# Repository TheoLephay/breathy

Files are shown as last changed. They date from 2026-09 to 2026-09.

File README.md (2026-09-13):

# Breathy

Work in progress.

An IOT esp32-based, battery powered, air quality monitor.

Since this is the least original project but I still needed one, I decided to make the li-ion charger myself as a challenge with discreet components.

Hardware design sheets available under `hardware/breathy/` folder. SPICE sim under `hardware/spice_sims/`.

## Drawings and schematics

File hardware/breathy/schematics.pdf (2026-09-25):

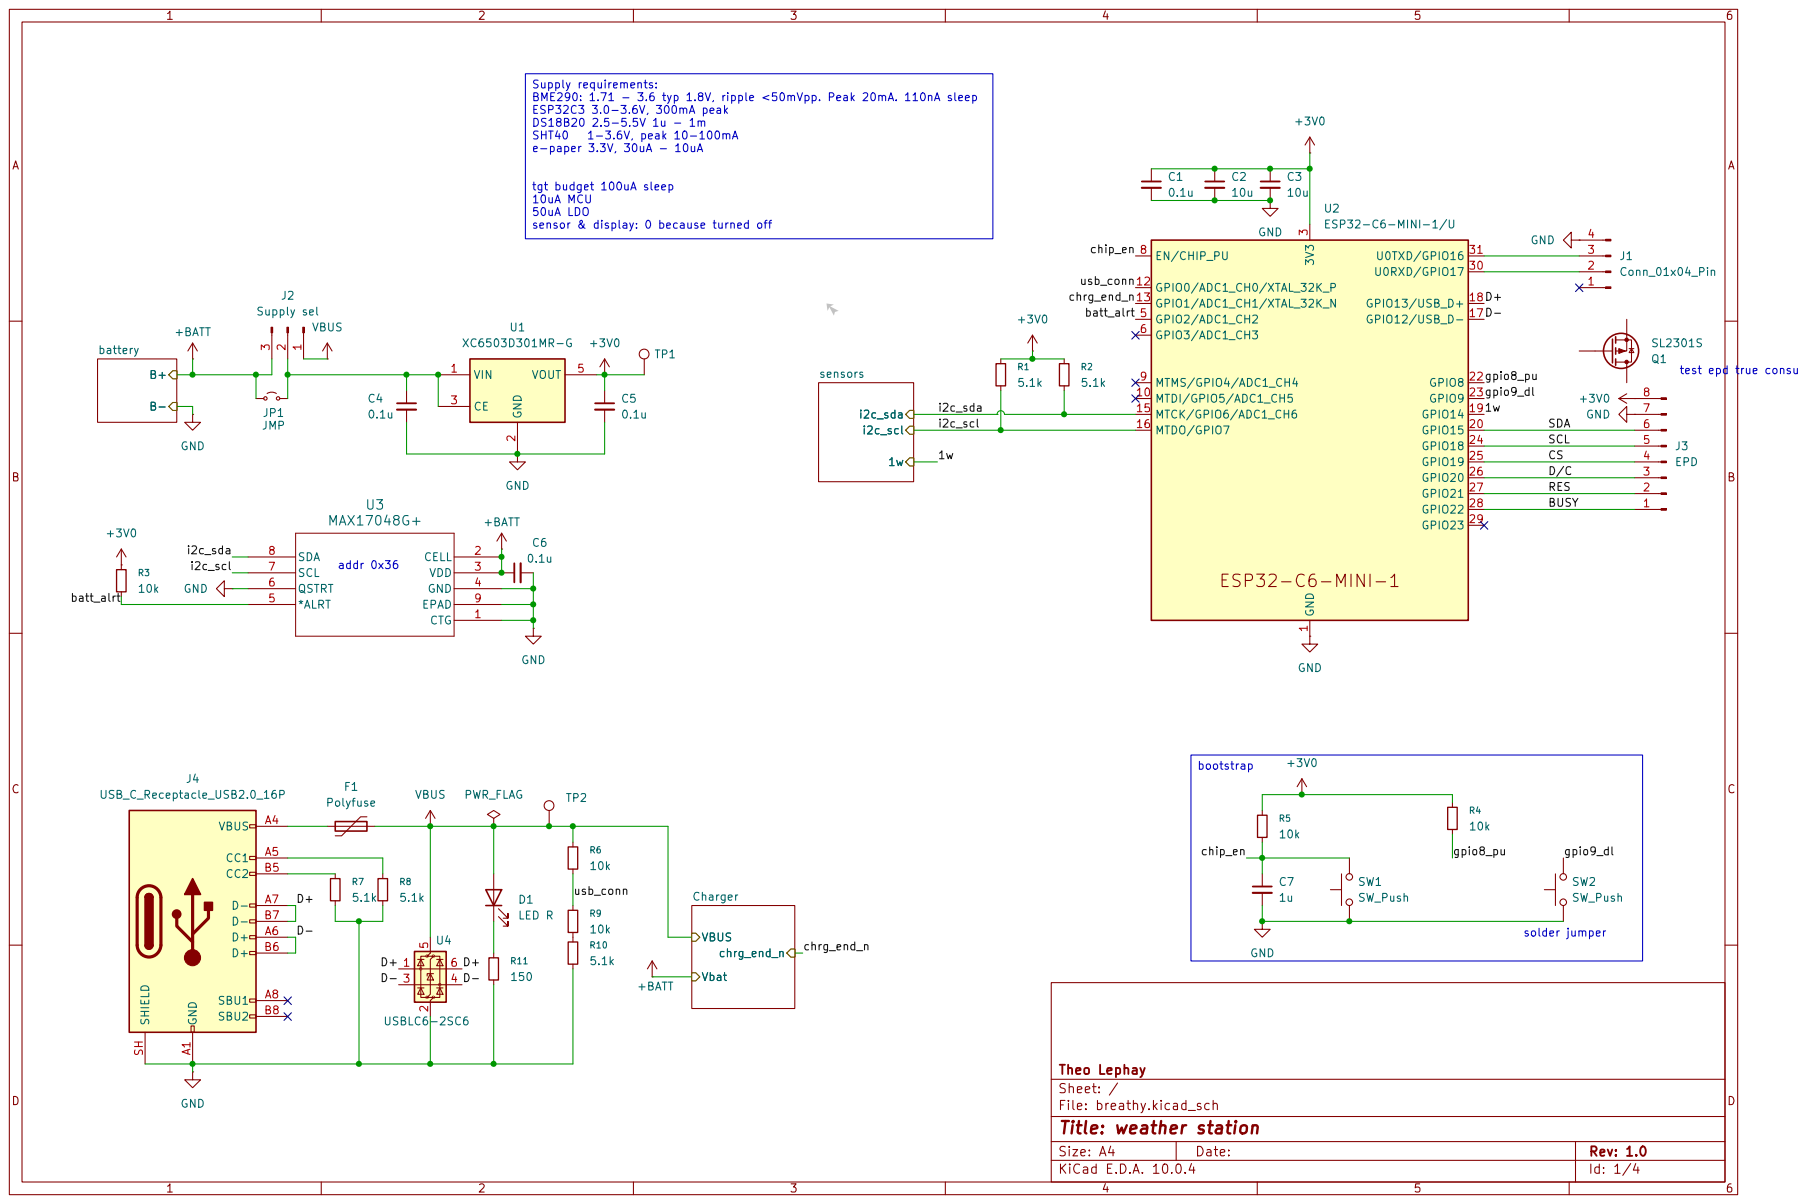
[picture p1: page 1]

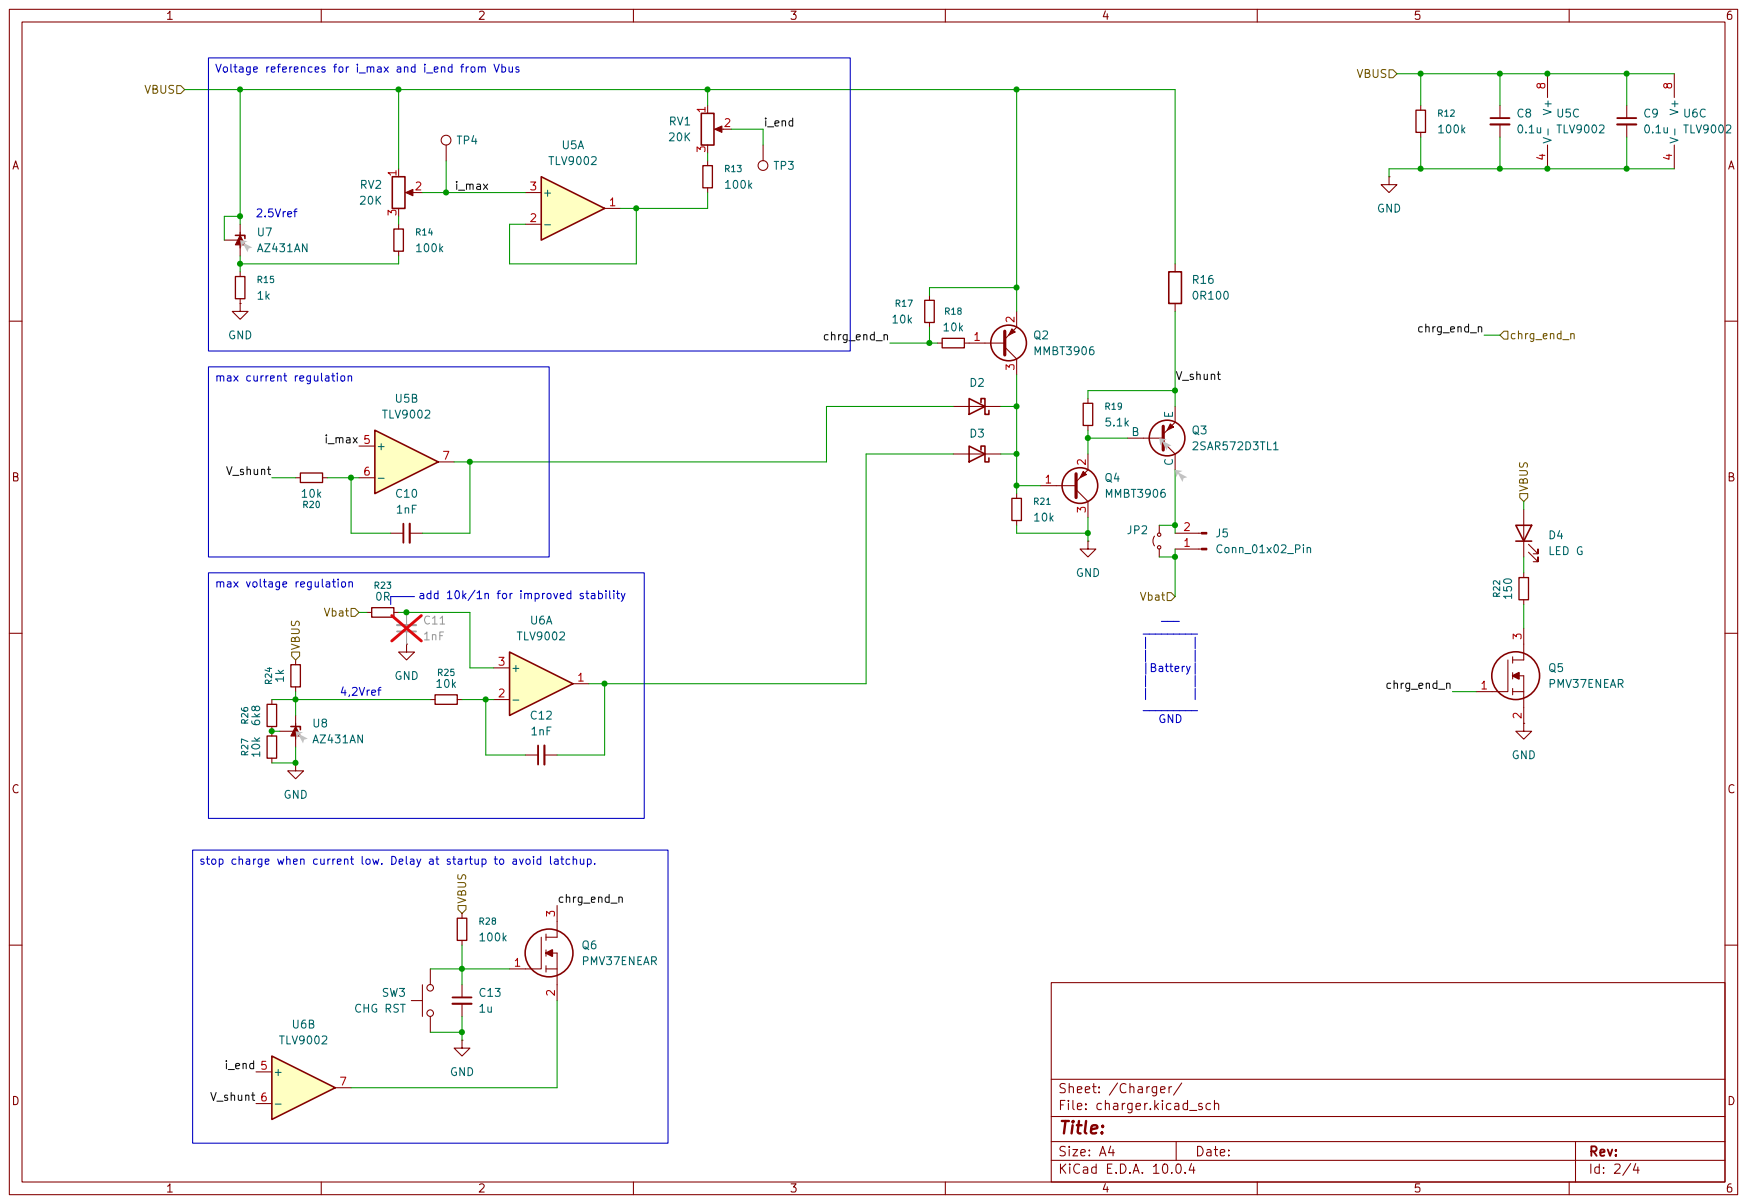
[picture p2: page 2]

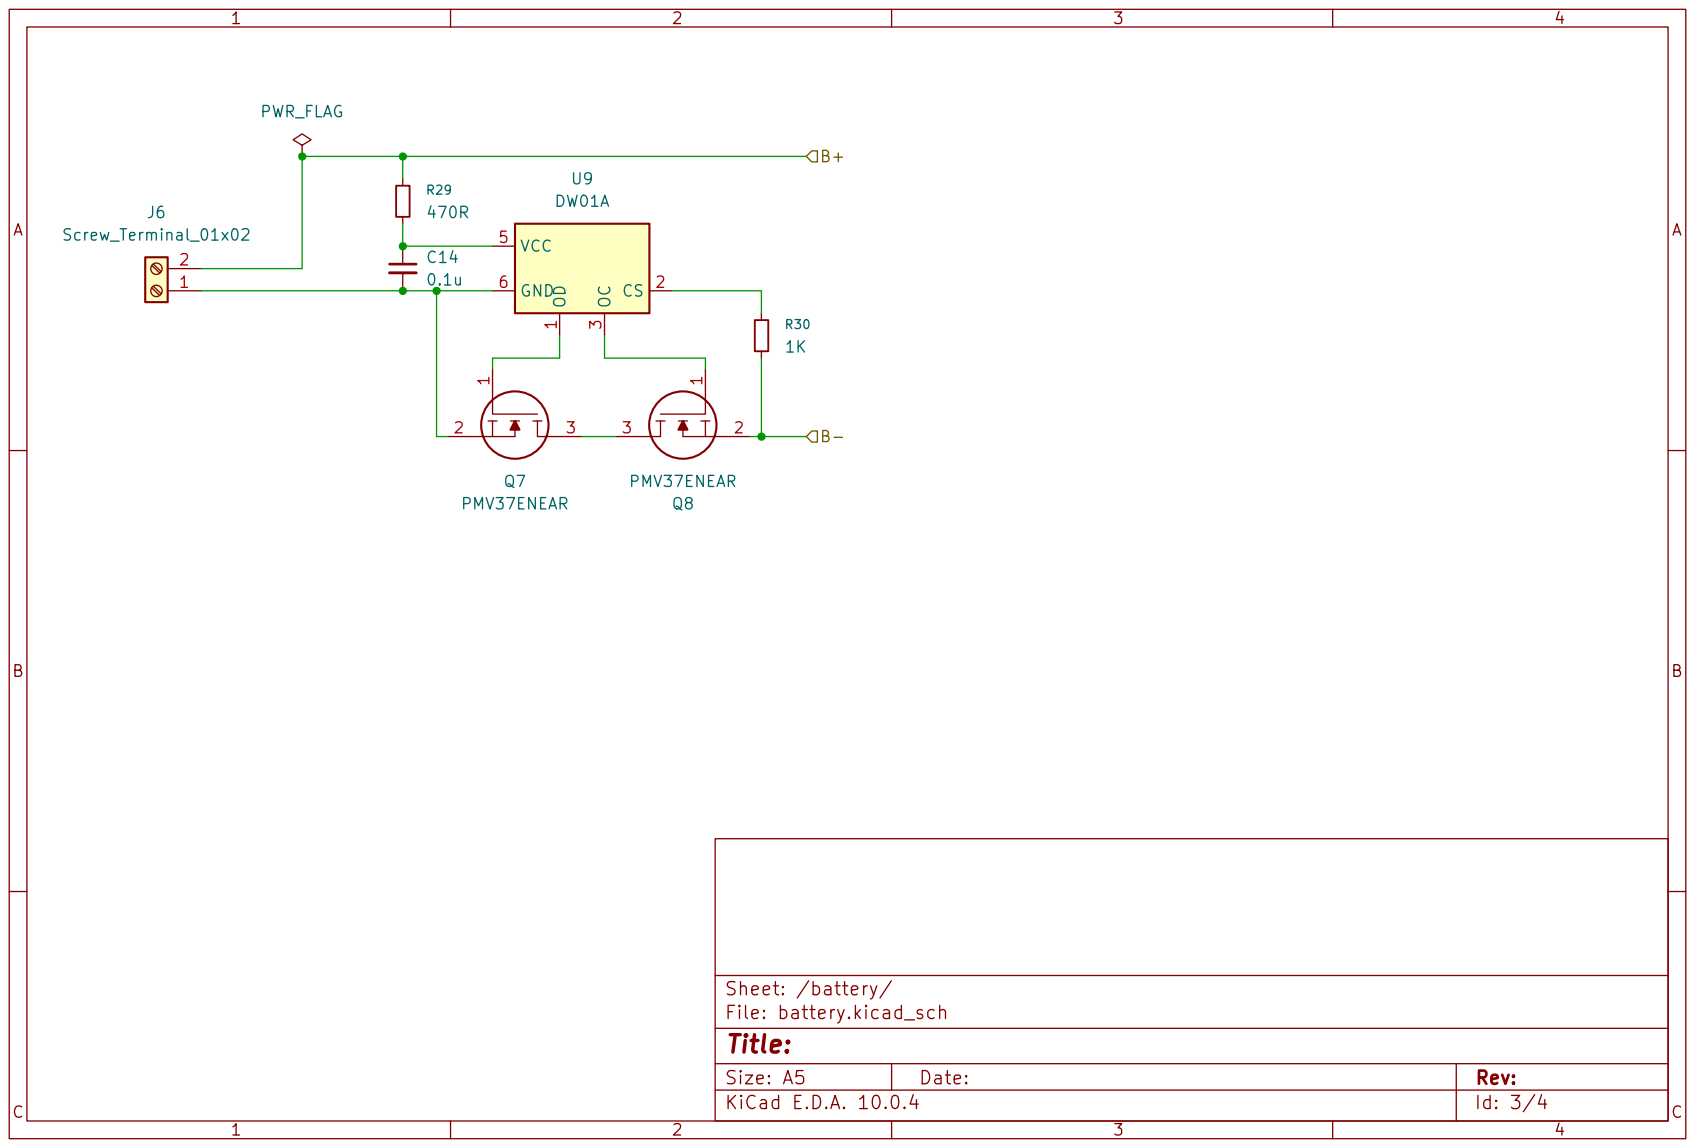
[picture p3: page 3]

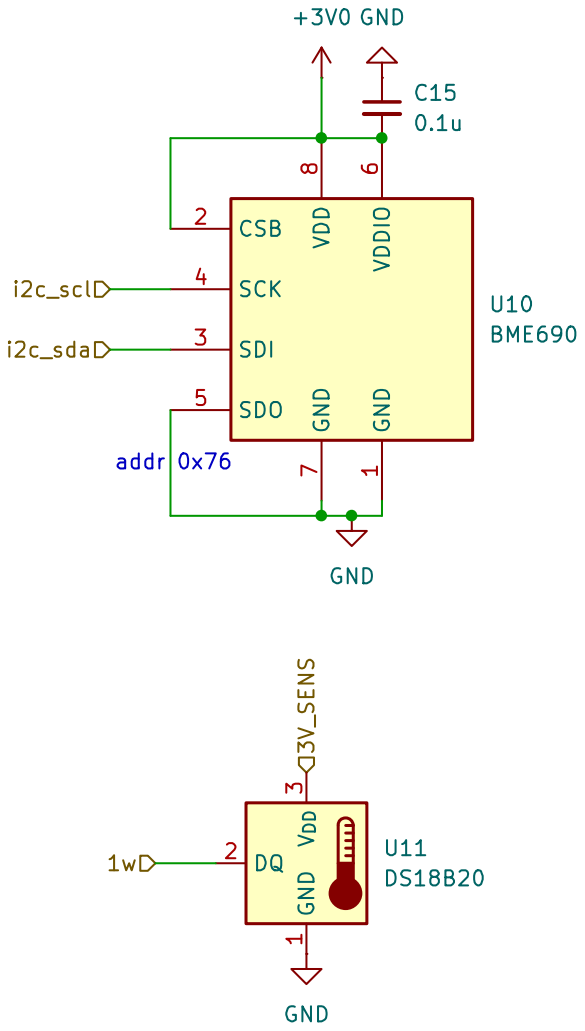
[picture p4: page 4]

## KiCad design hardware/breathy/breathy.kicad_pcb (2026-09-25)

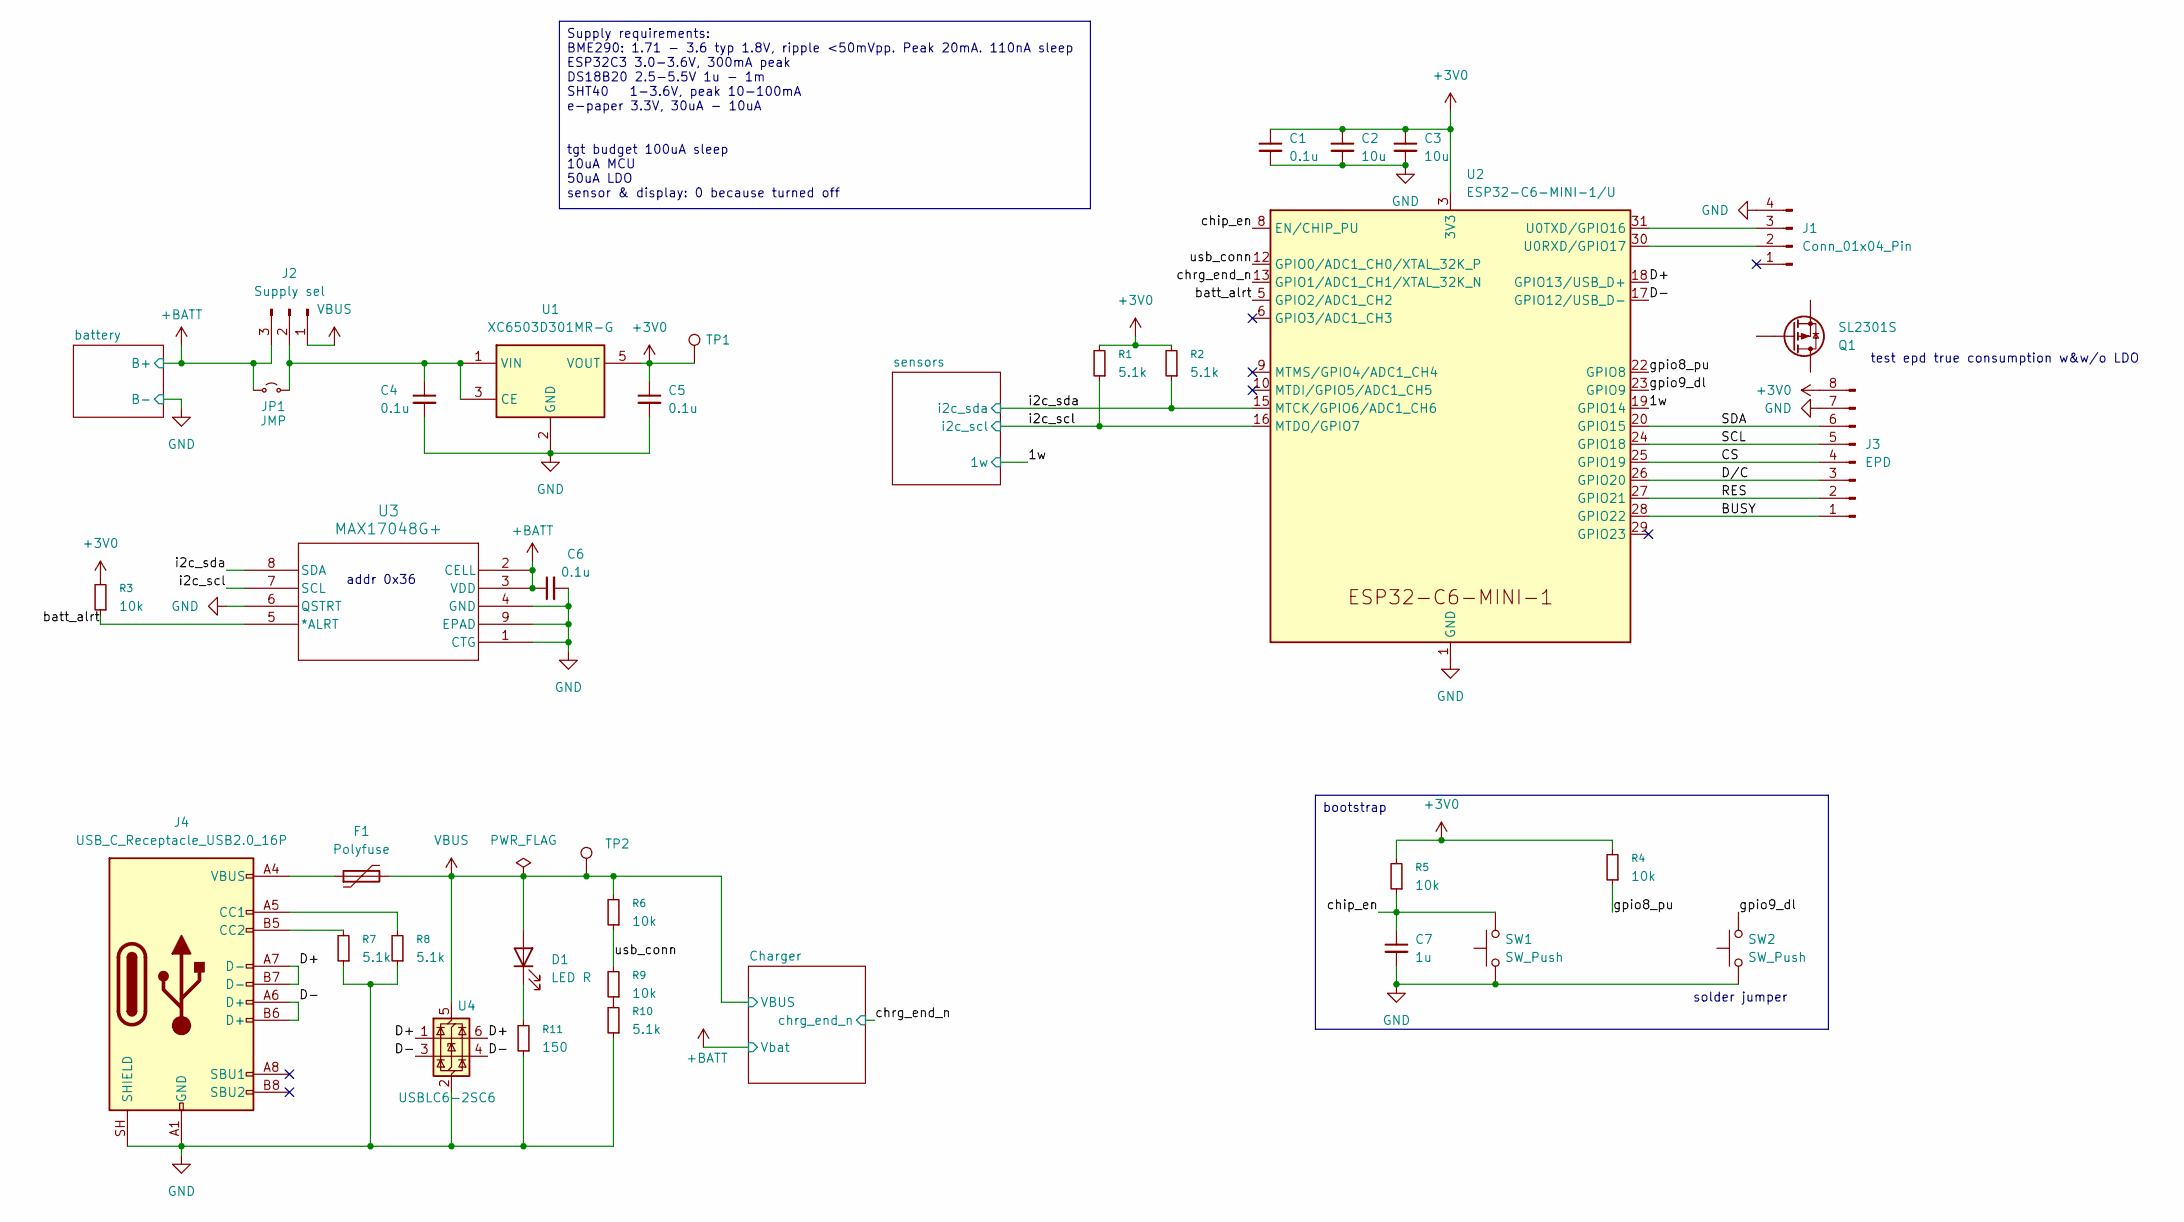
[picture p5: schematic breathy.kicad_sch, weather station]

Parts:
C1, C4, C5, C6: 0.1u; C_0805_2012Metric
C2, C3: 10u; C_1206_3216Metric
C7: 1u; C_1206_3216Metric
D1: LED R; LED_1206_3216Metric
F1: Polyfuse; C_1206_3216Metric
J1: Conn_01x04_Pin; PinHeader_1x04_P2.54mm_Vertical
J2: Supply sel; PinHeader_1x03_P2.54mm_Vertical
J3: EPD; PinHeader_1x08_P2.54mm_Horizontal
J4: USB_C_Receptacle_USB2.0_16P; USB_C_Receptacle_GCT_USB4105-xx-A_16P_TopMnt_Horizontal
JP1: JMP; SolderJumper-2_P1.3mm_Open_TrianglePad1.0x1.5mm
Q1: SL2301S; SOT-23
R1, R2, R7, R8, R10: 5.1k; R_0805_2012Metric
R3, R4, R5, R6, R9: 10k; R_0805_2012Metric
R11: 150; R_0805_2012Metric
SW1: SW_Push; SW_Push_1P1T_NO_CK_KSC9xxG
SW2: SW_Push; SolderJumper-2_P1.3mm_Open_TrianglePad1.0x1.5mm
TP1, TP2: TestPoint; TestPoint_Pad_D1.5mm
U1: XC6503D301MR-G; SC-74A-5_1.55x2.9mm_P0.95mm
U2: ESP32-C6-MINI-1/U; ESP32-C6-MINI-1
U3: MAX17048G+; 21-0168_T822&plus_3_MXM-M
U4: USBLC6-2SC6; SOT-23-6

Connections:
+3V0: C1.1, C2.1, C3.1, C5.1, J3.8, R1.2, R2.2, R3.2, R4.2, R5.2, TP1.1 (1_1), U1.5 (VOUT), U2.3 (3V3); also elsewhere on the board
+BATT: C6.1, J2.3, JP1.1 (A), U3.2 (CELL), U3.3 (VDD); also elsewhere on the board
/1w: U2.19 (GPIO14); also elsewhere on the board
/BUSY: J3.1, U2.28 (GPIO22)
/CS: J3.4, U2.25 (GPIO19)
/D+: J4.A7 (D-), J4.B7 (D-), U2.18 (GPIO13/USB_D+), U4.1 (I/O1), U4.6 (I/O1)
/D-: J4.A6 (D+), J4.B6 (D+), U2.17 (GPIO12/USB_D-), U4.3 (I/O2), U4.4 (I/O2)
/D/C: J3.3, U2.26 (GPIO20)
/RES: J3.2, U2.27 (GPIO21)
/SCL: J3.5, U2.24 (GPIO18)
/SDA: J3.6, U2.20 (GPIO15)
/batt_alrt: R3.1, U2.5 (GPIO2/ADC1_CH2), U3.5 (*ALRT)
/chip_en: C7.1, R5.1, SW1.2, U2.8 (EN/CHIP_PU)
/chrg_end_n: U2.13 (GPIO1/ADC1_CH1/XTAL_32K_N); also elsewhere on the board
/gpio8_pu: R4.1, U2.22 (GPIO8)
/gpio9_dl: SW2.2, U2.23 (GPIO9)
/i2c_scl: R1.1, U2.16 (MTDO/GPIO7), U3.7 (SCL); also elsewhere on the board
/i2c_sda: R2.1, U2.15 (MTCK/GPIO6/ADC1_CH6), U3.8 (SDA); also elsewhere on the board
/usb_conn: R6.1, R9.2, U2.12 (GPIO0/ADC1_CH0/XTAL_32K_P)
GND: C1.2, C2.2, C3.2, C4.2, C5.2, C6.2, C7.2, J1.4, J3.7, J4.A1 (GND), J4.A12 (GND), J4.B1 (GND), J4.B12 (GND), J4.SH (SHIELD), R7.1, R8.1, R10.1, R11.1, SW1.1, SW2.1, U1.2 (GND), U2.1 (GND), U2.2 (GND), U2.11 (GND), U2.14 (GND), U2.36 (GND), U2.37 (GND), U2.38 (GND), U2.39 (GND), U2.40 (GND), U2.41 (GND), U2.42 (GND), U2.43 (GND), U2.44 (GND), U2.45 (GND), U2.46 (GND), U2.47 (GND), U2.48 (GND), U2.49 (GND), U2.50 (GND), U2.51 (GND), U2.52 (GND), U2.53 (GND), U3.1 (CTG), U3.4 (GND), U3.6 (QSTRT), U3.9 (EPAD), U4.2 (GND); also elsewhere on the board
unnamed: D1.1 (K), R11.2
unnamed: F1.1, J4.A4 (VBUS), J4.A9 (VBUS), J4.B4 (VBUS), J4.B9 (VBUS)
unnamed: J1.2, U2.30 (U0RXD/GPIO17)
unnamed: J1.3, U2.31 (U0TXD/GPIO16)
unnamed: C4.1, J2.2, JP1.2 (B), U1.1 (VIN), U1.3 (CE)
unnamed: J4.A5 (CC1), R8.2
unnamed: J4.B5 (CC2), R7.2
unnamed: R9.1, R10.2
VBUS: D1.2 (A), F1.2, J2.1, R6.2, TP2.1 (1_1), U4.5 (VBUS); also elsewhere on the board

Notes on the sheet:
solder jumper
test epd true consumption w&w/o LDO
addr 0x36
Supply requirements: BME290: 1.71 - 3.6 typ 1.8V, ripple <50mVpp. Peak 20mA. 110nA sleep ESP32C3 3.0-3.6V, 300mA peak DS18B20 2.5-5.5V 1u - 1m SHT40 1-3.6V, peak 10-100mA e-paper 3.3V, 30uA - 10uA tgt budget 100uA sleep 10uA MCU 50uA LDO sensor & display: 0 because turned off
bootstrap

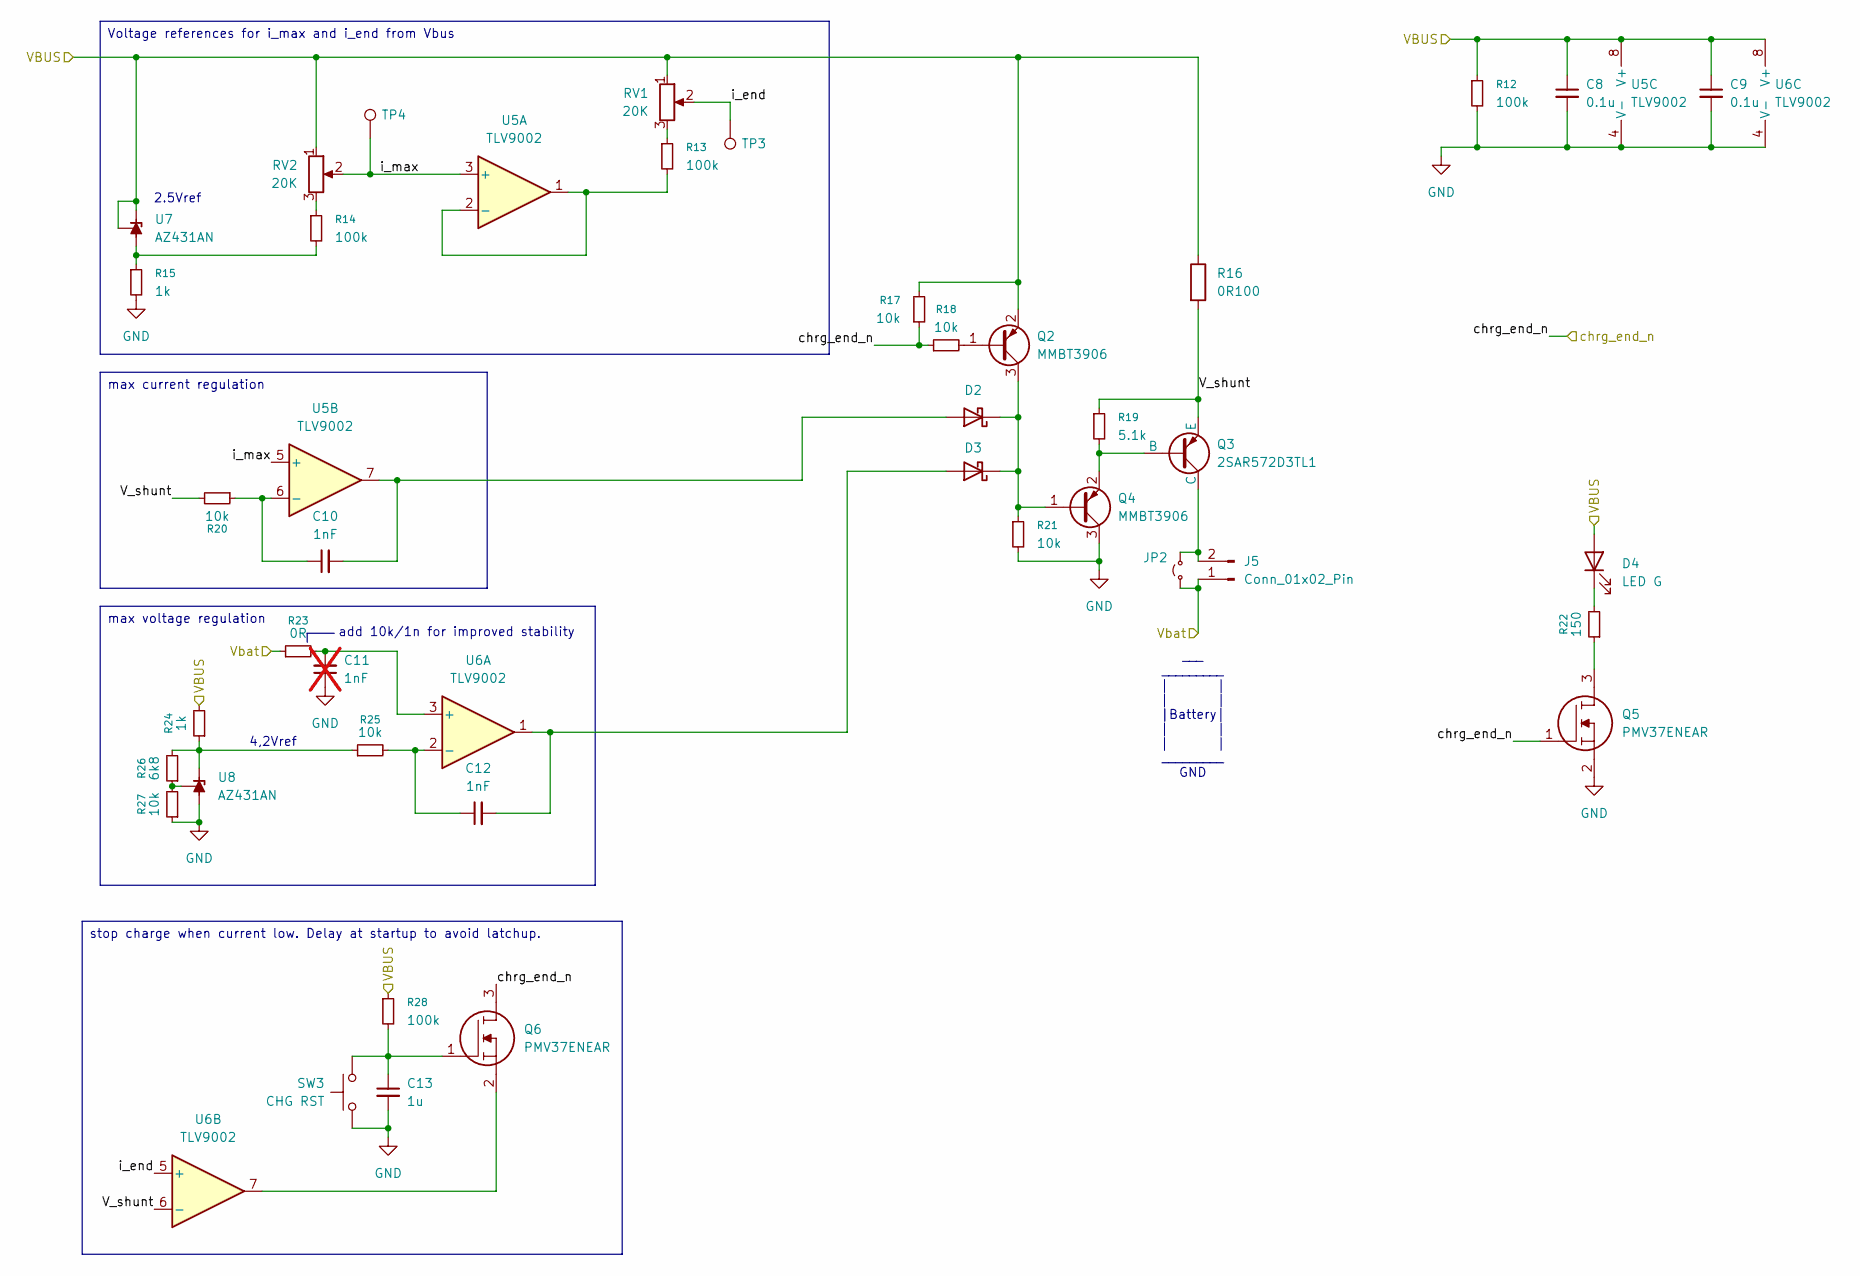
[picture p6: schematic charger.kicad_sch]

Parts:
C8, C9: 0.1u; C_0805_2012Metric
C10, C12: 1nF; C_0805_2012Metric
C11: 1nF; C_0805_2012Metric; not fitted
C13: 1u; C_1206_3216Metric
D2, D3: D_Schottky; D_SOD-323_HandSoldering
D4: LED G; LED_1206_3216Metric
J5: Conn_01x02_Pin; PinHeader_1x02_P2.54mm_Vertical
JP2: Jumper_2_Small_Open; SolderJumper-2_P1.3mm_Open_TrianglePad1.0x1.5mm
Q2, Q4: MMBT3906; SOT-23
Q3: 2SAR572D3TL1; TO-252-2
Q5, Q6: PMV37ENEAR; SOT95P230X110-3N; Mouser Part Number 771-PMV37ENEAR
R12, R13, R14, R28: 100k; R_1206_3216Metric
R15, R24: 1k; R_1206_3216Metric
R16: 0R100; R_2010_5025Metric_Pad1.40x2.65mm_HandSolder
R17, R18, R20, R21, R25, R27: 10k; R_0805_2012Metric
R19: 5.1k; R_0805_2012Metric
R22: 150; R_0805_2012Metric
R23: 0R; R_0805_2012Metric
R26: 6k8; R_0805_2012Metric
RV1, RV2: 20K; Potentiometer_Bourns_TC33X_Vertical
SW3: CHG RST; SW_Push_1P1T_NO_CK_KSC9xxG
TP3, TP4: TestPoint; TestPoint_Pad_D1.5mm
U5, U6: TLV9002; TSOT-23-8
U7, U8: AZ431AN; SOT-23

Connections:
+BATT: J5.1, JP2.1 (A), R23.1; also elsewhere on the board
/Charger/V_shunt: Q3.3 (E), R16.2, R19.1, R20.2, U6.6 (-)
/Charger/i_end: RV1.2, TP3.1 (1_1), U6.5 (+)
/Charger/i_max: RV2.2, TP4.1 (1_1), U5.3 (+), U5.5 (+)
/chrg_end_n: Q5.1, Q6.3, R17.1, R18.1; also elsewhere on the board
GND: C8.2, C9.2, C11.1, C13.2, Q4.3 (C), Q5.2, R12.2, R15.2, R21.2, R27.1, SW3.1, U5.4 (V-), U6.4 (V-), U8.3 (A); also elsewhere on the board
unnamed: C13.1, Q6.1, R28.2, SW3.2
unnamed: C10.2, D2.2 (A), U5.7
unnamed: D2.1 (K), D3.1 (K), Q2.3 (C), Q4.1 (B), R21.1
unnamed: C12.2, D3.2 (A), U6.1
unnamed: D4.1 (K), R22.2
unnamed: J5.2, JP2.2 (B), Q3.2 (C)
unnamed: Q2.1 (B), R18.2
unnamed: Q3.1 (B), Q4.2 (E), R19.2
unnamed: Q5.3, R22.1
unnamed: Q6.2, U6.7
unnamed: R13.1, RV1.3
unnamed: R14.1, RV2.3
unnamed: R13.2, U5.1, U5.2 (-)
unnamed: C10.1, R20.1, U5.6 (-)
unnamed: C11.2, R23.2, U6.3 (+)
unnamed: C12.1, R25.2, U6.2 (-)
unnamed: R14.2, R15.1, U7.3 (A)
unnamed: R24.1, R25.1, R26.2, U8.2 (K)
unnamed: R26.1, R27.2, U8.1 (REF)
VBUS: C8.1, C9.1, D4.2 (A), Q2.2 (E), R12.1, R16.1, R17.2, R24.2, R28.1, RV1.1, RV2.1, U5.8 (V+), U6.8 (V+), U7.1 (REF), U7.2 (K); also elsewhere on the board

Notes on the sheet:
___ _________ | | | | |Battery| | | | | _________ GND
2.5Vref
add 10k/1n for improved stability
4,2Vref
stop charge when current low. Delay at startup to avoid latchup.
Voltage references for i_max and i_end from Vbus
max current regulation
max voltage regulation

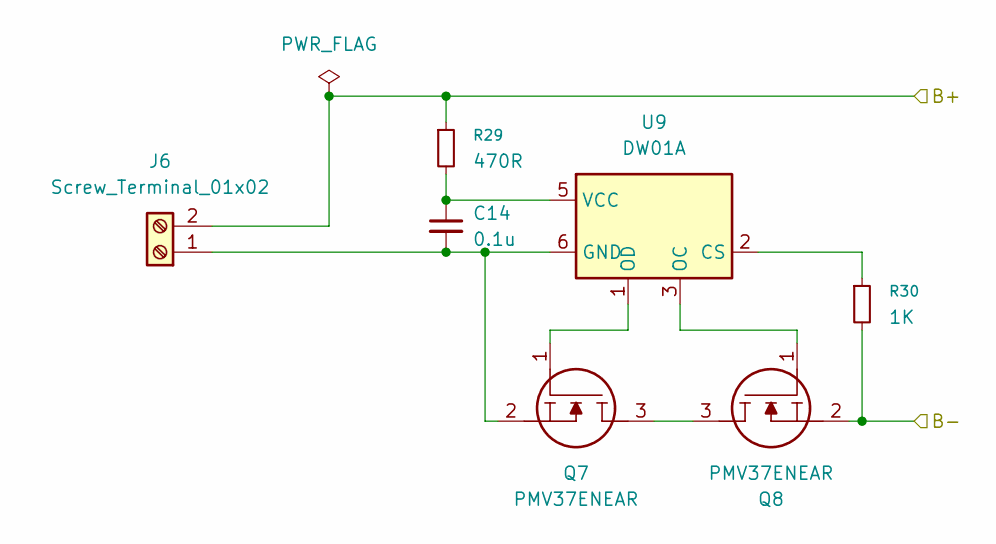
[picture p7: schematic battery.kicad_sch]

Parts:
C14: 0.1u; C_0805_2012Metric
J6: Screw_Terminal_01x02; TerminalBlock_MaiXu_MX126-5.0-02P_1x02_P5.00mm
Q7, Q8: PMV37ENEAR; SOT95P230X110-3N; Mouser Part Number 771-PMV37ENEAR
R29: 470R; R_0805_2012Metric
R30: 1K; R_1206_3216Metric
U9: DW01A; SOT-23-6

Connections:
+BATT: J6.2, R29.1; also elsewhere on the board
GND: Q8.2, R30.2; also elsewhere on the board
unnamed: C14.2, J6.1, Q7.2, U9.6 (GND)
unnamed: Q7.3, Q8.3
unnamed: R30.1, U9.2 (CS)
unnamed: Q8.1, U9.3 (OC)
unnamed: Q7.1, U9.1 (OD)
unnamed: C14.1, R29.2, U9.5 (VCC)

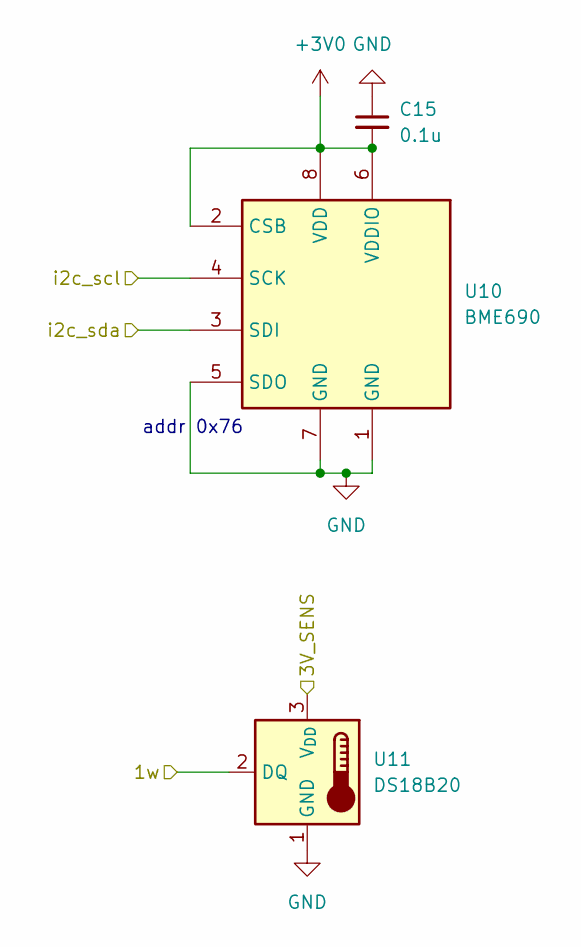
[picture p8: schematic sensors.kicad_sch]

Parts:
C15: 0.1u; C_0805_2012Metric
U10: BME690; Bosch_LGA-8_3x3mm_P0.8mm_ClockwisePinNumbering
U11: DS18B20; TO-92_Inline

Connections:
+3V0: C15.2, U10.2 (CSB), U10.6 (VDDIO), U10.8 (VDD); also elsewhere on the board
/1w: U11.2 (DQ); also elsewhere on the board
/i2c_scl: U10.4 (SCK); also elsewhere on the board
/i2c_sda: U10.3 (SDI); also elsewhere on the board
/sensors/3V_SENS: U11.3 (V_{DD})
GND: C15.1, U10.1 (GND), U10.5 (SDO), U10.7 (GND), U11.1 (GND); also elsewhere on the board

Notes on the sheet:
addr 0x76

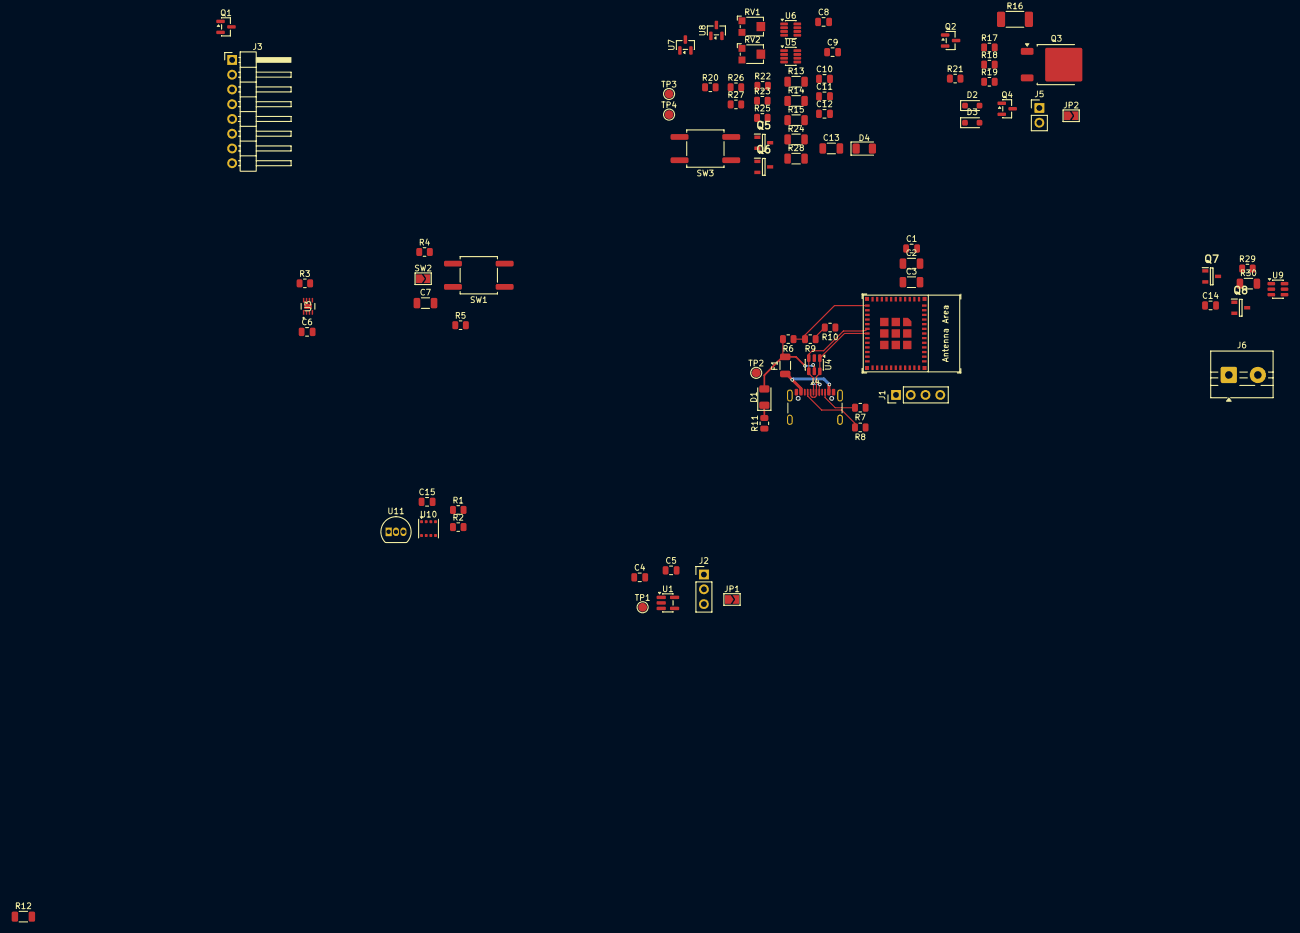
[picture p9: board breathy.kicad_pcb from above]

Board: 2 copper layers, 86 parts (0 on the bottom side), 57 nets.

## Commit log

2026-09-19 test points, headers, indicators, no battery sim
    [battery.kicad_sch, breathy.kicad_sch, charger.kicad_sch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]
2026-09-25 adding pdf schematics
    [battery.kicad_sch, breathy.kicad_pcb, breathy.kicad_sch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]
2026-10-30 block reverse current when charger is unplugged
2026-10-30 add powerpath
2026-10-30 change LDO for 3.3V, use correct DW01A FETs
2026-10-30 charge control from MCU
